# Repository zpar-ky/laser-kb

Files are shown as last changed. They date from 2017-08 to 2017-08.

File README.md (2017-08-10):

# Laser-85
### A GMK Laser inspired case, in a custom 85-key handwired ortholinear package.

## the plan  

Design and print case with http://builder.swillkb.com/, steel switchplate cut by Lasergist, acrylic cut by Ponoko.    
Philosophy for layers is the ability to only have to use one hand while using modifiers.  

| Layer | Type | Material | Width |
|:-----:|:---:|:---:|:-----:|
| 1 | Switch | Steel | 1.5mm |
| 2 | Closed | Purple Acrylic | ~3mm  |
| 3 | Open | Purple Acrylic | ~3mm  |
| 4 | Open | Blue Acrylic | ~4mm  |
| 5 | Closed | Purple Acrylic | ~3mm  |
| 6 | Closed | Purple Acrylic | ~3mm  |
| 7 | Bottom | Blue Acrylic | ~4mm  |
| | | Total Inside | ~13mm |
| | | Total | ~20mm |

swillkb settings:  
SwillKB Settings
underside design:  
LASER

## programming  
Teensy 2.0 planned pinout: (going from top left down)  
B1, B2, B3, B7, D0, D1, D2, D3, D5, C6, C7, D5, D7, B4, B5, B6, F7, F6, F5, F4, F1, F0  
gives 22 pins for 17x5 matrix  
Build with http://kbfirmware.com/ as base and then edit the rest according to qmk standards

Itemlist
------

| Item | Product name | Price | Link | Comments |
|:---|:---:|:---:|:---:|:---|
| Switches | Gateron blacks | $24.99  | [link](https://www.massdrop.com/buy/gateron-switches) | Bought from massdrop |
| Diodes | 1N4148 diode | $5.99 | [link](https://www.amazon.com/gp/product/B06XB1R2NK)  | 300pcs |
| Insulated Wire | Striveday 22AWG | $7.99 | [link](https://www.amazon.com/gp/product/B01IBAIL60)  | 5m purple |
| Solder | Sywon 60/40 | $7.99 | [link](https://www.amazon.com/gp/product/B01LVTTL9E)  | 0.039" dia, 50g |
| Soldering Tool | Sywon 60w kit | $32.99  | [link](https://www.amazon.com/gp/product/B01N4571Q6)  | includes temp control  |
| Wire Stripper  | Irwin Vise-Grip | $10.70  | [link](https://www.amazon.com/gp/product/B000JNNWQ2)  | |
| Spacers | M2/M3 Brass Standoffs | $14.99  | [link](https://www.amazon.com/gp/product/B00MNG2T6W)  | yeah this was overkill |
| Screws | Rion Tech Screw Kit | $9.99 | [link](https://www.amazon.com/gp/product/B072NZY69F)  | similarly overkill |
| USB Extender | YCS Basics Mini-B M-F | $7.99 | [link](https://www.amazon.com/gp/product/B01CKMGD10)  | |
| Controller | Teensy 2.0 | $20.95  | [link](https://www.amazon.com/gp/product/B00NC43256)  | |
| Switch plate | Cut by lasergist | $81.34  | [link](https://www.lasergist.com) | they ship from Greece  |
| Acrylics | Cut by ponoko | $91.07  | [link](https://www.ponoko.com) | first shot |
| Acrylics | Cut by ponoko | $54.92  | [link](https://www.ponoko.com) | second shot |
| Keycap Set | GMK Laser | $??.??  | [link](https://www.massdrop.com/talk/455/laser-gmk) | |
| Total | | $371.9  | | not including caps yet |

Total would be less if tools are already owned, and also some items (like 300 pack of diodes) aren't used in entirety and the real cost is less

Final thoughts
------

## guides used  
https://www.reddit.com/r/MechanicalKeyboards/comments/4l0p41/guide_detailed_guide_to_making_a_custom_keyboard/  
https://github.com/qmk/qmk_firmware/blob/0787d70e55a668244445d9328f3cda2303cc6877/docs/hand_wire.md  
https://github.com/ruiqimao/keyboard-pcb-guide

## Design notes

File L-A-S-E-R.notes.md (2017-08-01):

A GMK Laser inspired case, in a custom 85-key handwired ortholinear package.

Design and print case with http://builder.swillkb.com/ , cuts by lasergist  
Philosophy for layers is the ability to use only one hand for lower and raise keys.  
The display plan is have the top display be what it will physically look like, and the bottom copy to be what the layers will be  
Unfortunately, all the novelty caps are R1, which might look bad on R4. I'll have to see what it comes out to look like, and if anything, go with the planck blanks.

Plan:  
Switch plate: Cut switch plate with lasergist @ 1.5mm  
Acrylic sandwich + bottom: Cut 2 open plates, 3 closed plates, and 1 bottom plate @ ~3mm each from Ponoko (Ponoko uses inches) to have ~12mm of inside space  
Total case height = ~15mm  
Colors: Blue open layer, Purple tint closed layers, Blue bottom layer

swillkb settings: http://i.imgur.com/jhe3P6L.jpg  
underside design:   

guide: https://www.reddit.com/r/MechanicalKeyboards/comments/4l0p41/guide_detailed_guide_to_making_a_custom_keyboard/  

edit after getting acrylics:
didn't have enough space with 4 ~3mm thick acrylics, so ordered another open layer that's like ~4mm or so. Also didn't like the way the LASER looked on the bottom plate, so reversed it and ordered it along with the ~4mm open layer. Both are the blue tint, and so far it's going to be:  
[ switch - closed -  open  - open - closed - closed - bottom ]  
[ steel  - purple - purple - blue - purple - purple -  blue  ]

Good news is the spacers and screws I ordered fit perfectly. However, I top-switched the gateron clear with cherry black tops for aesthetic and I think those don't fit as snugly in the switch plate as I hoped. I'm going to leave it as-is and be careful if I ever remove the caps. If I ever need to hot glue the switches I'll be pissed  

Teensy 2.0 planned pinout: (going from top left down)  
B0, B1, B2, B3, B7, D0, D1, D2, D3, C6, C7, D5, D7, B4, B5, B6, F7, F6, F5, F4, F1, F0  
gives 22 pins for 17x5 matrix  
Build with http://kbfirmware.com/

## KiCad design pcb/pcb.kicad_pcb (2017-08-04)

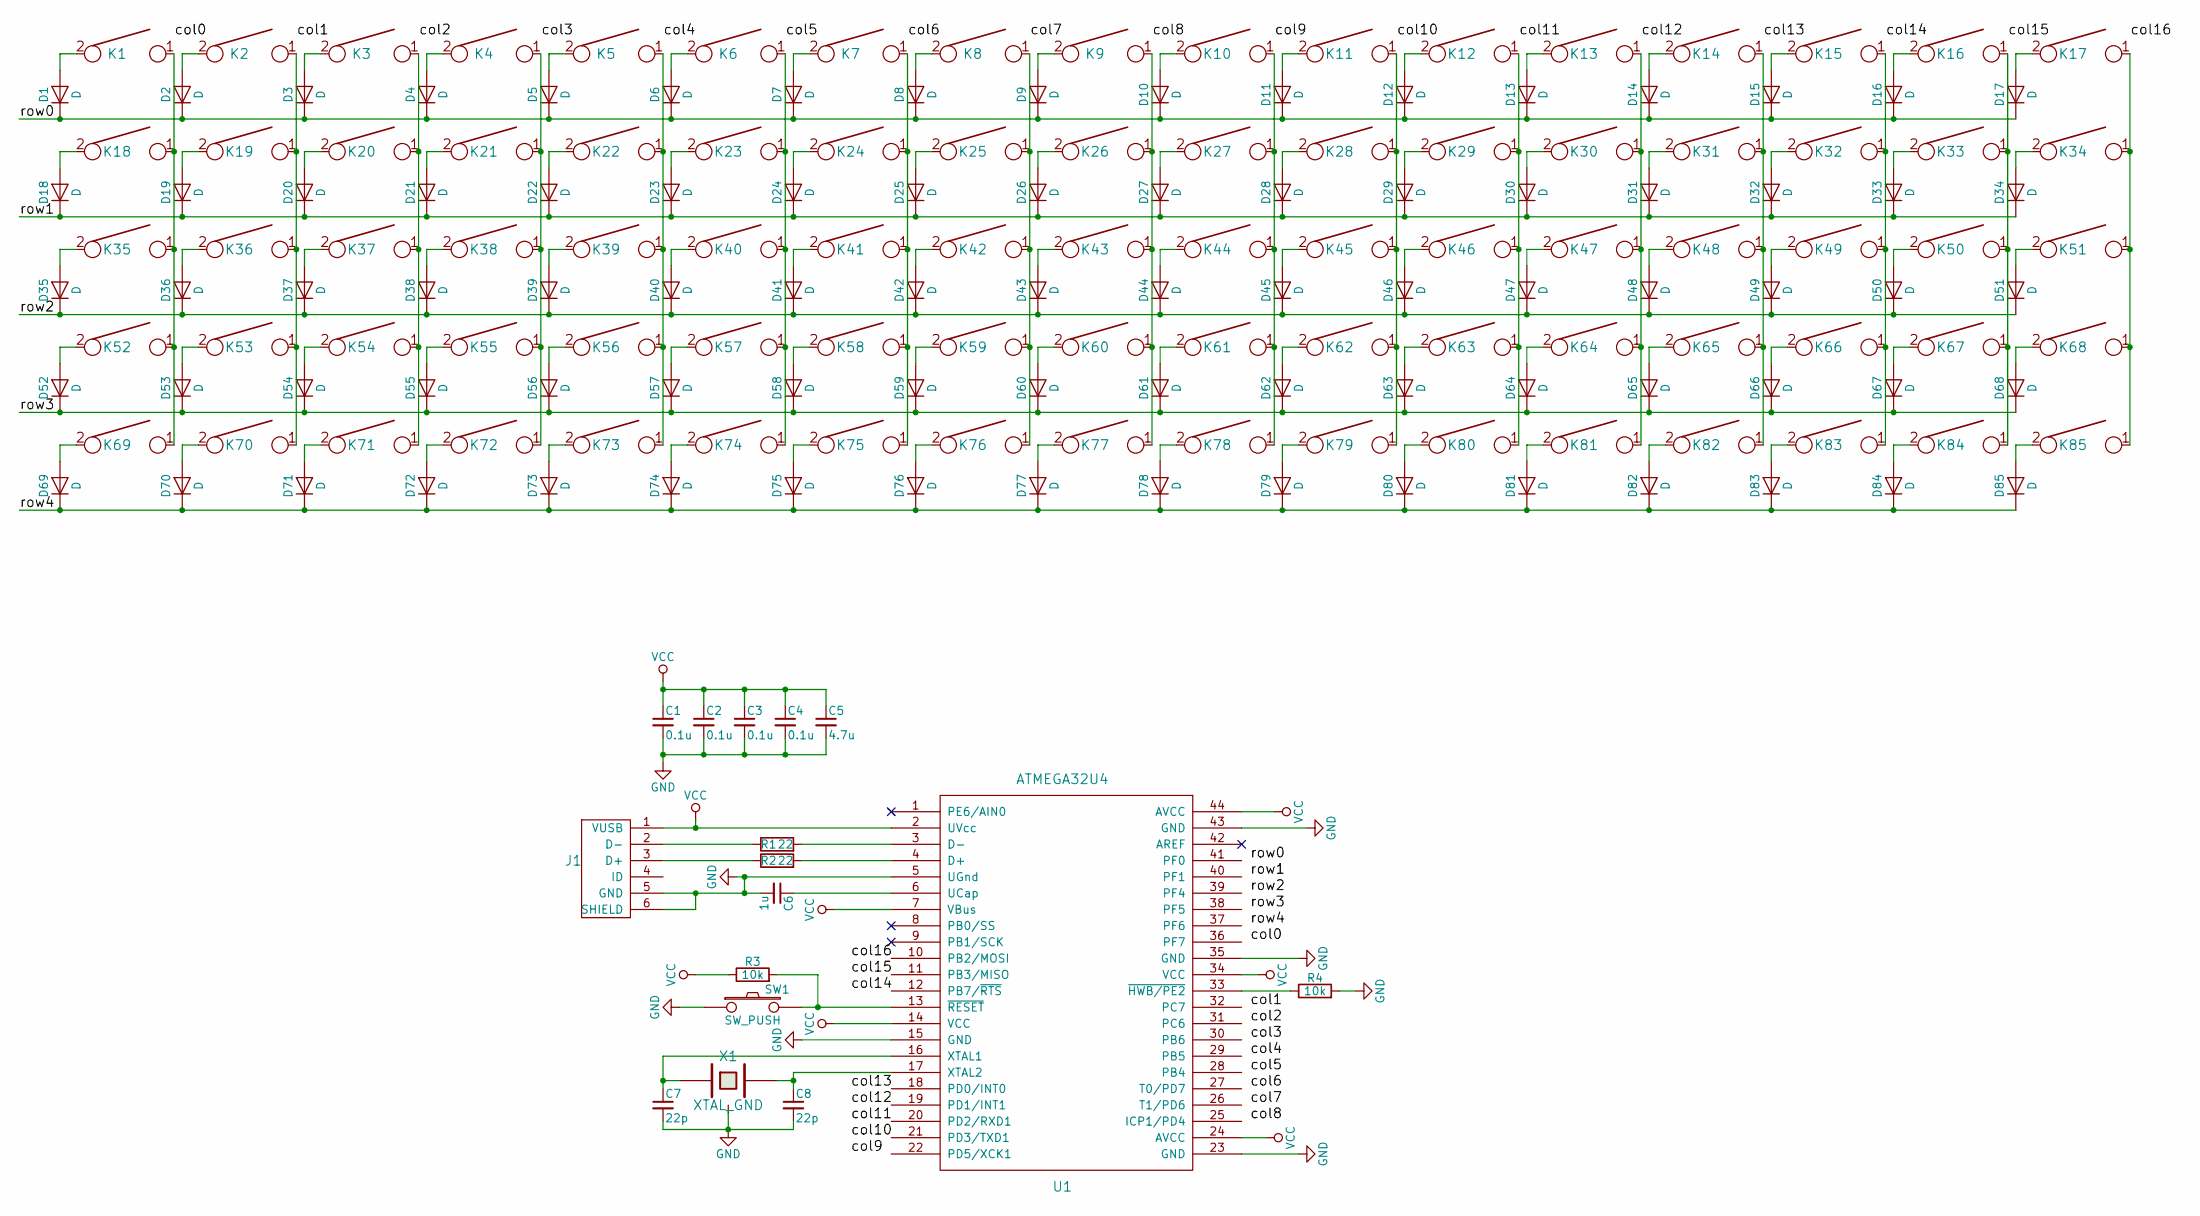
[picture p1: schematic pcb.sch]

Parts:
C1, C2, C3, C4: 0.1u; C_0805_HandSoldering
C5: 4.7u; C_0805_HandSoldering
C6: 1u; C_0805_HandSoldering
C7, C8: 22p; C_0805_HandSoldering
D1, D2, D3, D4, D5, D6, D7, D8, D9, D10, D11, D12, D13, D14, D15, D16, D17, D18, D19, D20, D21, D22, D23, D24, D25, D26, D27, D28, D29, D30, D31, D32, D33, D34, D35, D36, D37, D38, D39, D40, D41, D42, D43, D44, D45, D46, D47, D48, D49, D50, D51, D52, D53, D54, D55, D56, D57, D58, D59, D60, D61, D62, D63, D64, D65, D66, D67, D68, D69, D70, D71, D72, D73, D74, D75, D76, D77, D78, D79, D80, D81, D82, D83, D84, D85: D; D_SOD123_axial
J1: USB_mini_micro_B; USB_miniB_hirose_5S8
K1, K2, K3, K4, K5, K6, K7, K8, K9, K10, K11, K12, K13, K14, K15, K16, K17, K18, K19, K20, K21, K22, K23, K24, K25, K26, K27, K28, K29, K30, K31, K32, K33, K34, K35, K36, K37, K38, K39, K40, K41, K42, K43, K44, K45, K46, K47, K48, K49, K50, K51, K52, K53, K54, K55, K56, K57, K58, K59, K60, K61, K62, K63, K64, K65, K66, K67, K68, K69, K70, K71, K72, K73, K74, K75, K76, K77, K78, K79, K80, K81, K82, K83, K84, K85: KEYSW; Mx_Alps_100
R1, R2: 22; R_0805_HandSoldering
R3, R4: 10k; R_0805_HandSoldering
SW1: SW_PUSH; SW_SPST_TL3342
U1: ATMEGA32U4; LQFP-44_10x10mm_Pitch0.8mm
X1: XTAL_GND; FA-238

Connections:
/row0: D1.1 (K), D2.1 (K), D3.1 (K), D4.1 (K), D5.1 (K), D6.1 (K), D7.1 (K), D8.1 (K), D9.1 (K), D10.1 (K), D11.1 (K), D12.1 (K), D13.1 (K), D14.1 (K), D15.1 (K), D16.1 (K), D17.1 (K)
/row1: D18.1 (K), D19.1 (K), D20.1 (K), D21.1 (K), D22.1 (K), D23.1 (K), D24.1 (K), D25.1 (K), D26.1 (K), D27.1 (K), D28.1 (K), D29.1 (K), D30.1 (K), D31.1 (K), D32.1 (K), D33.1 (K), D34.1 (K)
/row2: D35.1 (K), D36.1 (K), D37.1 (K), D38.1 (K), D39.1 (K), D40.1 (K), D41.1 (K), D42.1 (K), D43.1 (K), D44.1 (K), D45.1 (K), D46.1 (K), D47.1 (K), D48.1 (K), D49.1 (K), D50.1 (K), D51.1 (K)
/row3: D52.1 (K), D53.1 (K), D54.1 (K), D55.1 (K), D56.1 (K), D57.1 (K), D58.1 (K), D59.1 (K), D60.1 (K), D61.1 (K), D62.1 (K), D63.1 (K), D64.1 (K), D65.1 (K), D66.1 (K), D67.1 (K), D68.1 (K)
/row4: D69.1 (K), D70.1 (K), D71.1 (K), D72.1 (K), D73.1 (K), D74.1 (K), D75.1 (K), D76.1 (K), D77.1 (K), D78.1 (K), D79.1 (K), D80.1 (K), D81.1 (K), D82.1 (K), D83.1 (K), D84.1 (K), D85.1 (K)
GND: C1.2, C2.2, C3.2, C4.2, C5.2, C6.2, C7.2, C8.2, J1.5 (GND), J1.6 (SHIELD), R4.2, SW1.1, U1.5 (UGnd), U1.15 (GND), U1.23 (GND), U1.35 (GND), U1.43 (GND), X1.3
unnamed: C6.1, U1.6 (UCap)
unnamed: C7.1, U1.16 (XTAL1), X1.1
unnamed: C8.1, U1.17 (XTAL2), X1.2
unnamed: D1.2 (A), K1.2
unnamed: D2.2 (A), K2.2
unnamed: D3.2 (A), K3.2
unnamed: D4.2 (A), K4.2
unnamed: D5.2 (A), K5.2
unnamed: D6.2 (A), K6.2
unnamed: D7.2 (A), K7.2
unnamed: D8.2 (A), K8.2
unnamed: D9.2 (A), K9.2
unnamed: D10.2 (A), K10.2
unnamed: D11.2 (A), K11.2
unnamed: D12.2 (A), K12.2
unnamed: D13.2 (A), K13.2
unnamed: D14.2 (A), K14.2
unnamed: D15.2 (A), K15.2
unnamed: D16.2 (A), K16.2
unnamed: D17.2 (A), K17.2
unnamed: D18.2 (A), K18.2
unnamed: D19.2 (A), K19.2
unnamed: D20.2 (A), K20.2
unnamed: D21.2 (A), K21.2
unnamed: D22.2 (A), K22.2
unnamed: D23.2 (A), K23.2
unnamed: D24.2 (A), K24.2
unnamed: D25.2 (A), K25.2
unnamed: D26.2 (A), K26.2
unnamed: D27.2 (A), K27.2
unnamed: D28.2 (A), K28.2
unnamed: D29.2 (A), K29.2
unnamed: D30.2 (A), K30.2
unnamed: D31.2 (A), K31.2
unnamed: D32.2 (A), K32.2
unnamed: D33.2 (A), K33.2
unnamed: D34.2 (A), K34.2
unnamed: D35.2 (A), K35.2
unnamed: D36.2 (A), K36.2
unnamed: D37.2 (A), K37.2
unnamed: D38.2 (A), K38.2
unnamed: D39.2 (A), K39.2
unnamed: D40.2 (A), K40.2
unnamed: D41.2 (A), K41.2
unnamed: D42.2 (A), K42.2
unnamed: D43.2 (A), K43.2
unnamed: D44.2 (A), K44.2
unnamed: D45.2 (A), K45.2
unnamed: D46.2 (A), K46.2
unnamed: D47.2 (A), K47.2
unnamed: D48.2 (A), K48.2
unnamed: D49.2 (A), K49.2
unnamed: D50.2 (A), K50.2
unnamed: D51.2 (A), K51.2
unnamed: D52.2 (A), K52.2
unnamed: D53.2 (A), K53.2
unnamed: D54.2 (A), K54.2
unnamed: D55.2 (A), K55.2
unnamed: D56.2 (A), K56.2
unnamed: D57.2 (A), K57.2
unnamed: D58.2 (A), K58.2
unnamed: D59.2 (A), K59.2
unnamed: D60.2 (A), K60.2
unnamed: D61.2 (A), K61.2
unnamed: D62.2 (A), K62.2
unnamed: D63.2 (A), K63.2
unnamed: D64.2 (A), K64.2
unnamed: D65.2 (A), K65.2
unnamed: D66.2 (A), K66.2
unnamed: D67.2 (A), K67.2
unnamed: D68.2 (A), K68.2
unnamed: D69.2 (A), K69.2
unnamed: D70.2 (A), K70.2
unnamed: D71.2 (A), K71.2
unnamed: D72.2 (A), K72.2
unnamed: D73.2 (A), K73.2
unnamed: D74.2 (A), K74.2
unnamed: D75.2 (A), K75.2
unnamed: D76.2 (A), K76.2
unnamed: D77.2 (A), K77.2
unnamed: D78.2 (A), K78.2
unnamed: D79.2 (A), K79.2
unnamed: D80.2 (A), K80.2
unnamed: D81.2 (A), K81.2
unnamed: D82.2 (A), K82.2
unnamed: D83.2 (A), K83.2
unnamed: D84.2 (A), K84.2
unnamed: D85.2 (A), K85.2
unnamed: J1.2 (D-), R1.1
unnamed: J1.3 (D+), R2.1
unnamed: K1.1, K18.1, K35.1, K52.1, K69.1
unnamed: K10.1, K27.1, K44.1, K61.1, K78.1
unnamed: K11.1, K28.1, K45.1, K62.1, K79.1
unnamed: K12.1, K29.1, K46.1, K63.1, K80.1
unnamed: K13.1, K30.1, K47.1, K64.1, K81.1
unnamed: K14.1, K31.1, K48.1, K65.1, K82.1
unnamed: K15.1, K32.1, K49.1, K66.1, K83.1
unnamed: K16.1, K33.1, K50.1, K67.1, K84.1
unnamed: K17.1, K34.1, K51.1, K68.1, K85.1
unnamed: K2.1, K19.1, K36.1, K53.1, K70.1
unnamed: K3.1, K20.1, K37.1, K54.1, K71.1
unnamed: K4.1, K21.1, K38.1, K55.1, K72.1
unnamed: K5.1, K22.1, K39.1, K56.1, K73.1
unnamed: K6.1, K23.1, K40.1, K57.1, K74.1
unnamed: K7.1, K24.1, K41.1, K58.1, K75.1
unnamed: K8.1, K25.1, K42.1, K59.1, K76.1
unnamed: K9.1, K26.1, K43.1, K60.1, K77.1
unnamed: R1.2, U1.3 (D-)
unnamed: R2.2, U1.4 (D+)
unnamed: R3.2, SW1.2, U1.13 (~RESET)
unnamed: R4.1, U1.33 (~HWB/PE2)
VCC: C1.1, C2.1, C3.1, C4.1, C5.1, J1.1 (VUSB), R3.1, U1.2 (UVcc), U1.7 (VBus), U1.14 (VCC), U1.24 (AVCC), U1.34 (VCC), U1.44 (AVCC)

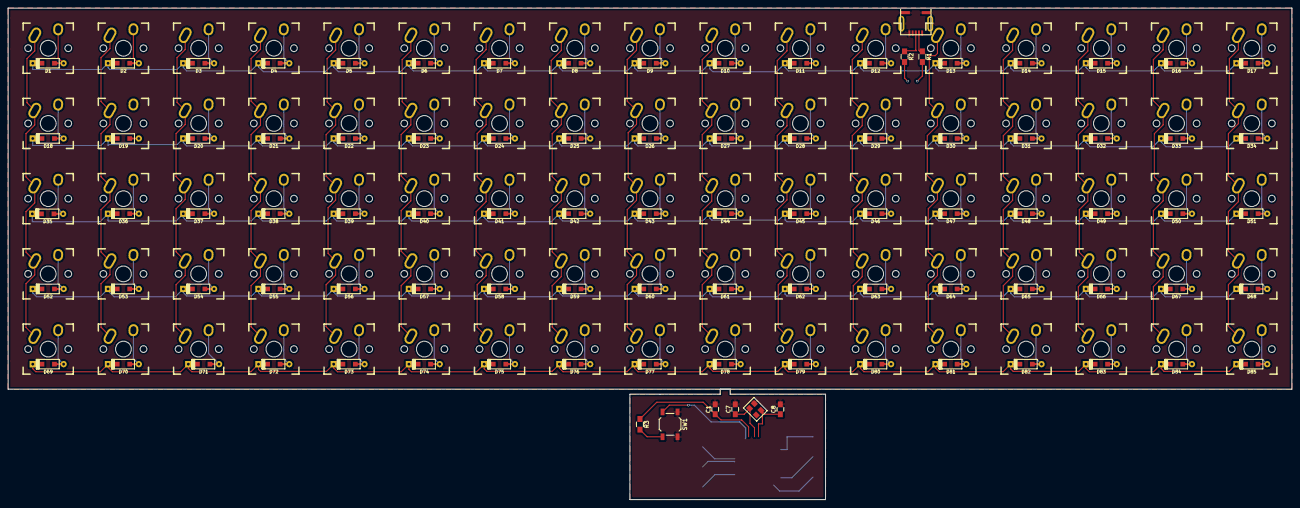
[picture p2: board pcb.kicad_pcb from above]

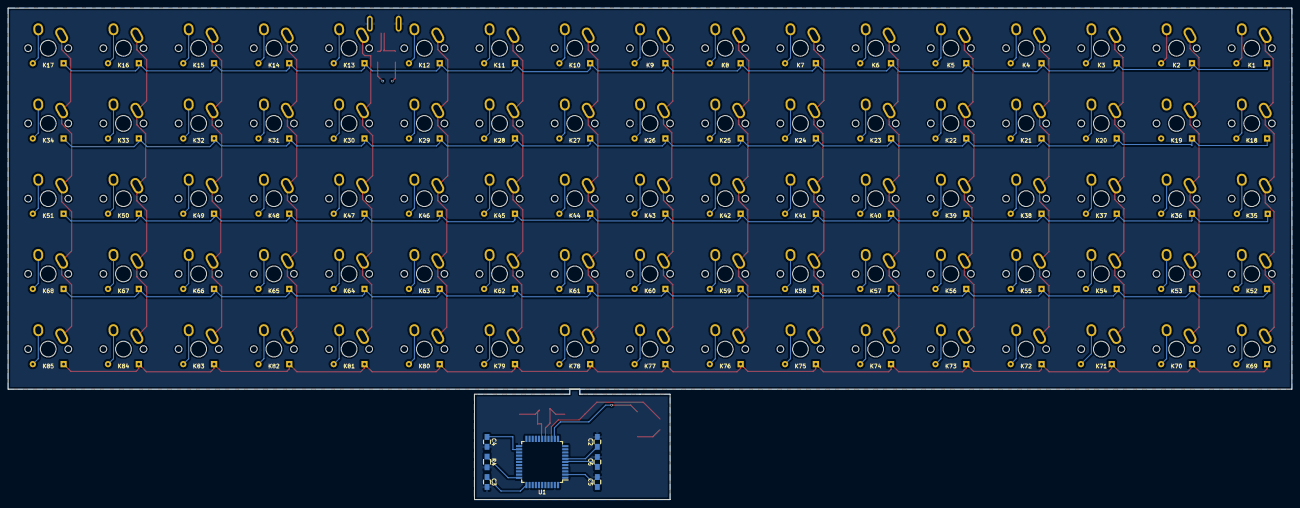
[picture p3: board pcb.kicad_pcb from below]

Board: 2 copper layers, 325.1 x 96.5 mm, 186 parts (7 on the bottom side), 118 nets.

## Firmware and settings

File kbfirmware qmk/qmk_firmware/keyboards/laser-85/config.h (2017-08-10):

#ifndef CONFIG_H
#define CONFIG_H

#include "config_common.h"

/* USB Device descriptor parameter */
#define VENDOR_ID       0x1739
#define PRODUCT_ID      0x1739
#define DEVICE_VER      0x0001
#define MANUFACTURER    Sparky
#define PRODUCT         Laser-85
#define DESCRIPTION     a 85 key ortholinear

/* key matrix size */
#define MATRIX_ROWS 5
#define MATRIX_COLS 17

/* key matrix pins */
//#define MATRIX_ROW_PINS { B1, B2, B3, B7, D0 }
#define MATRIX_ROW_PINS { D0, B7, B3, B2, B1 }
#define MATRIX_COL_PINS { D1, D2, D3, C6, C7, D5, D4, D7, B4, B5, B6, F7, F6, F5, F4, F1, F0 }
//#define MATRIX_COL_PINS { F0, F1, F4, F5, F6, F7, B6, B5, B4, D7, D4, D5, C7, C6, D3, D2, D1 }
#define UNUSED_PINS { B0, E6, D6 } 

/* COL2ROW or ROW2COL */
#define DIODE_DIRECTION COL2ROW

/* number of backlight levels */

#ifdef BACKLIGHT_PIN
#define BACKLIGHT_LEVELS 0
#endif

/* Set 0 if debouncing isn't needed */
#define DEBOUNCING_DELAY 5

/* Mechanical locking support. Use KC_LCAP, KC_LNUM or KC_LSCR instead in keymap */
#define LOCKING_SUPPORT_ENABLE

/* Locking resynchronize hack */
#define LOCKING_RESYNC_ENABLE

/* key combination for command */
#define IS_COMMAND() ( \
    keyboard_report->mods == (MOD_BIT(KC_LSHIFT) | MOD_BIT(KC_RSHIFT)) \
)

/* prevent stuck modifiers */
#define PREVENT_STUCK_MODIFIERS


#ifdef RGB_DI_PIN
#define RGBLIGHT_ANIMATIONS
#define RGBLED_NUM 0
#define RGBLIGHT_HUE_STEP 8
#define RGBLIGHT_SAT_STEP 8
#define RGBLIGHT_VAL_STEP 8
#endif

#endif

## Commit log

2017-08-02 Add other keyboard layouts
    haha ten million changed files
2017-08-03 Added PCB files
    [pcb int chip.kicad_pcb, pcb.kicad_pcb, pcb.sch]
2017-08-04 Updated PCB
    added tracks for all the switches (whew!)
    [pcb.kicad_pcb]
2017-08-04 Updated PCB
    pcb is unfinished and will need serious tuneups to get it off the ground, if I ever do so
    [pcb.kicad_pcb]
2017-08-04 removed some pcb files
    [pcb int chip.kicad_pcb]
2017-08-10 Update and fix qmk config + hex files
    [config.h]
2017-08-10 update to fit my garbage wiring
